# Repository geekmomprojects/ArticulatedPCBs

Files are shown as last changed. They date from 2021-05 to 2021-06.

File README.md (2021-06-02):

# Articulated PCBs (aka "Bendy Boards")
Design files and BOM for an articulated assembly of PCBs comprised of two-layered links that can pivot around a vertical axis, allowing the assembly to bend at every joint while still maintaining electrical contact between all of the boards in the assembly.<BR>
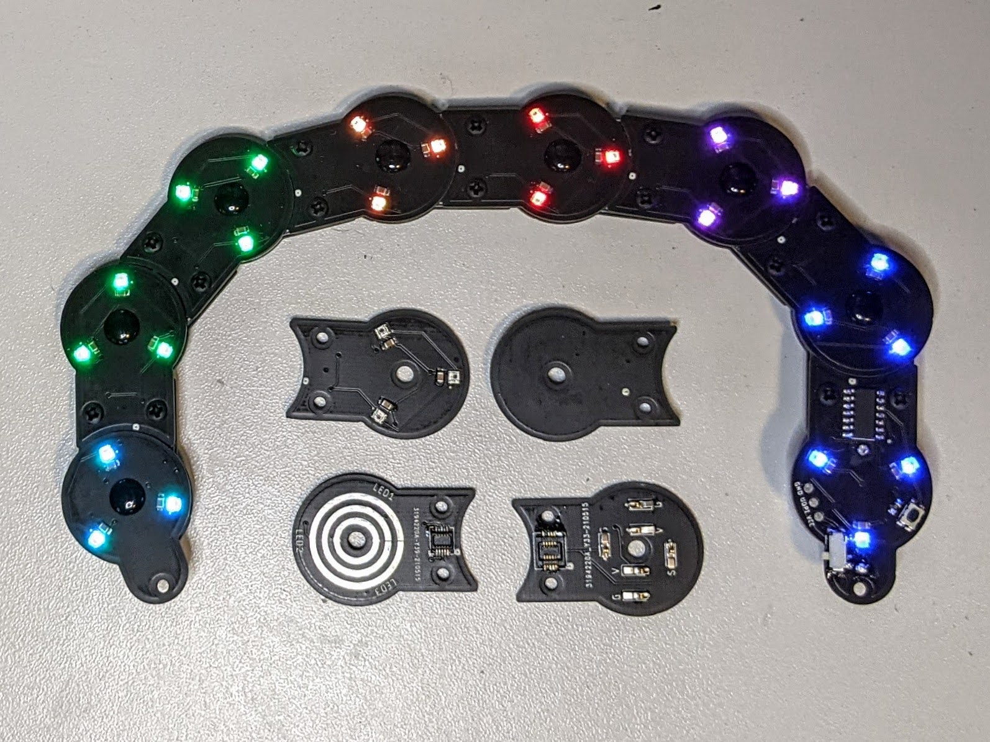
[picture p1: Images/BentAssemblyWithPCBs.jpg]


A demonstration of the boards and the assembly is on <a href="https://www.youtube.com/watch?v=9HDyzVgGNhk">YouTube:<BR> 
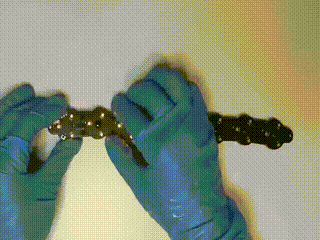
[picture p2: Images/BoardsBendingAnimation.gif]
</a>

The two layers of each link connect through pressure connectors on the bottom PCB which make contact with cocentric ring-shaped pads on the top one. A laser-cut buffer layer of 1.6mm (1/16") acrylic between the two PCBs prevents the connectors from being crushed. The connectors have a working height of 1.7 mm, which prevents the connectors from being crushed between the PCBs. The layers in the link are held together with an M3 nylon push rivet. Vertical board-to-board snap connectors connect each link to the previous one in the chain. The mating height of these snap connectors is about 1.5 mm, so the spacing between the PCB layers is the same everywhere.<BR>
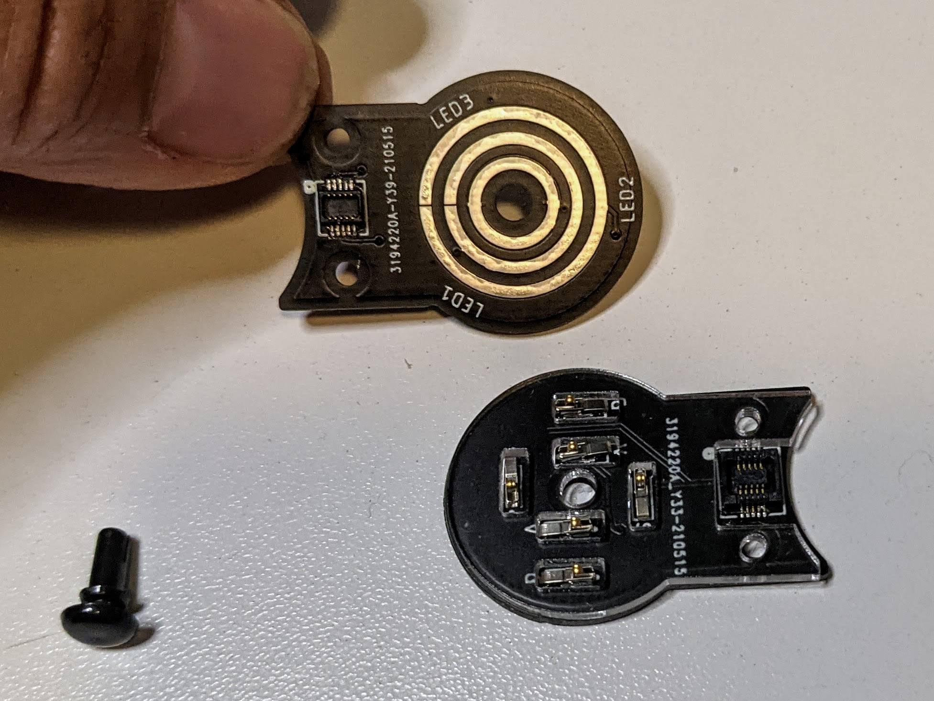
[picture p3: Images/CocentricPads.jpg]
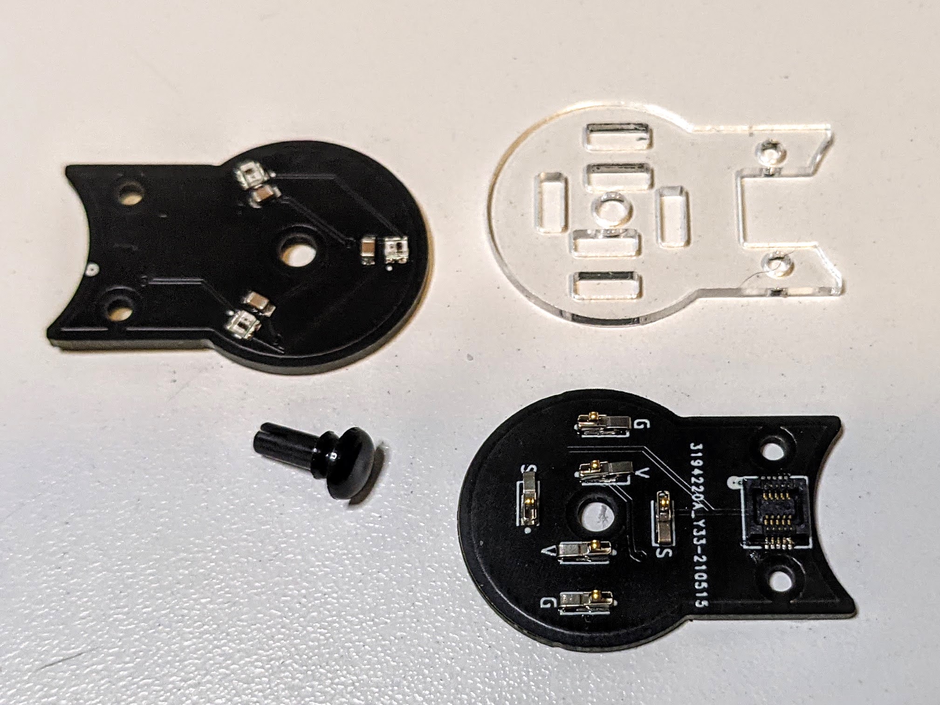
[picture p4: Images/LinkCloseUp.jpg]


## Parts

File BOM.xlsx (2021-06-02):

PCB Components | Quantity | Part Number | Datasheet | Source
WS2812 or sk6812 2020 LEDs (5 mA best) | 3 per link | WS2812 2020 |  | https://www.aliexpress.com/item/32876876257.html
0603 0.1uF capacitors | 3 per link | EMK107B7104KAHT | https://www.mouser.com/datasheet/2/396/taiyo_yuden_12132018_mlcc11_hq_e-1510082.pdf | https://www.mouser.com/ProductDetail/Taiyo-Yuden/EMK107B7104KAHT
Pressure Contacts | 6 per link | 10104319-009RLF | https://cdn.amphenol-icc.com/media/wysiwyg/files/drawing/10104319.pdf | https://www.digikey.com/product-detail/en/amphenol-icc-fci/10104319-009RLF/609-5377-1-ND/8555648
ATTiny 1604 or 1614 controller IC | 1 per assembly |  | https://www.mouser.com/datasheet/2/268/ATtiny804_1604_Data_Sheet_40002028A-1588519.pdf | https://www.mouser.com/ProductDetail/Microchip-Technology/ATTINY1604-SSNR
Slide Switch | 1 per assembly | PCM12SMTR | https://www.mouser.com/datasheet/2/60/pcm-1841544.pdf | https://www.mouser.com/ProductDetail/CK/PCM12SMTR
2xCR2032 battery holder | 1 per assembly | BH800s | https://media.digikey.com/pdf/Data%20Sheets/Memory%20Protection%20PDFs/Coin_Cell_Guide.pdf | https://www.digikey.com/en/products/detail/mpd-memory-protection-devices/BH800S/221549
Momentary push button | 1 per assembly | KMR211GLFS | https://www.ckswitches.com/media/1479/kmr2.pdf | https://www.digikey.com/en/products/detail/c-k/KMR211GLFS/550461
Board to Board connector (plug) | 1 per link | DF23C-10DS-0.5V(51) | https://www.hirose.com/product/download/?distributor=digikey&type=specSheet&lang=en&num=DF23C-10DS-0.5V(51) | https://www.digikey.com/en/products/detail/hirose-electric-co-ltd/DF23C-10DS-0.5V(51)/5155992
Board to Board connector (receptacle) | 1 per link | DF23C-10DP-0.5V(92) | https://www.hirose.com/product/download/?distributor=digikey&type=specSheet&lang=en&num=DF23C-10DP-0.5V(92) | https://www.digikey.com/en/products/detail/hirose-electric-co-ltd/DF23C-10DP-0.5V(92)/3830805
Hardware
6mm or 8mm M2 screws | 2 per link
M2 nuts | 2 per link
M3 Plastic Push Rivets for panel thickness of 5.8 mm | 1 per link |  |  | https://www.amazon.com/gp/product/B07RGKP96K
Materials
1/16" (1.6mm) acrylic for laser-cut buffer layer | 1 buffer per link

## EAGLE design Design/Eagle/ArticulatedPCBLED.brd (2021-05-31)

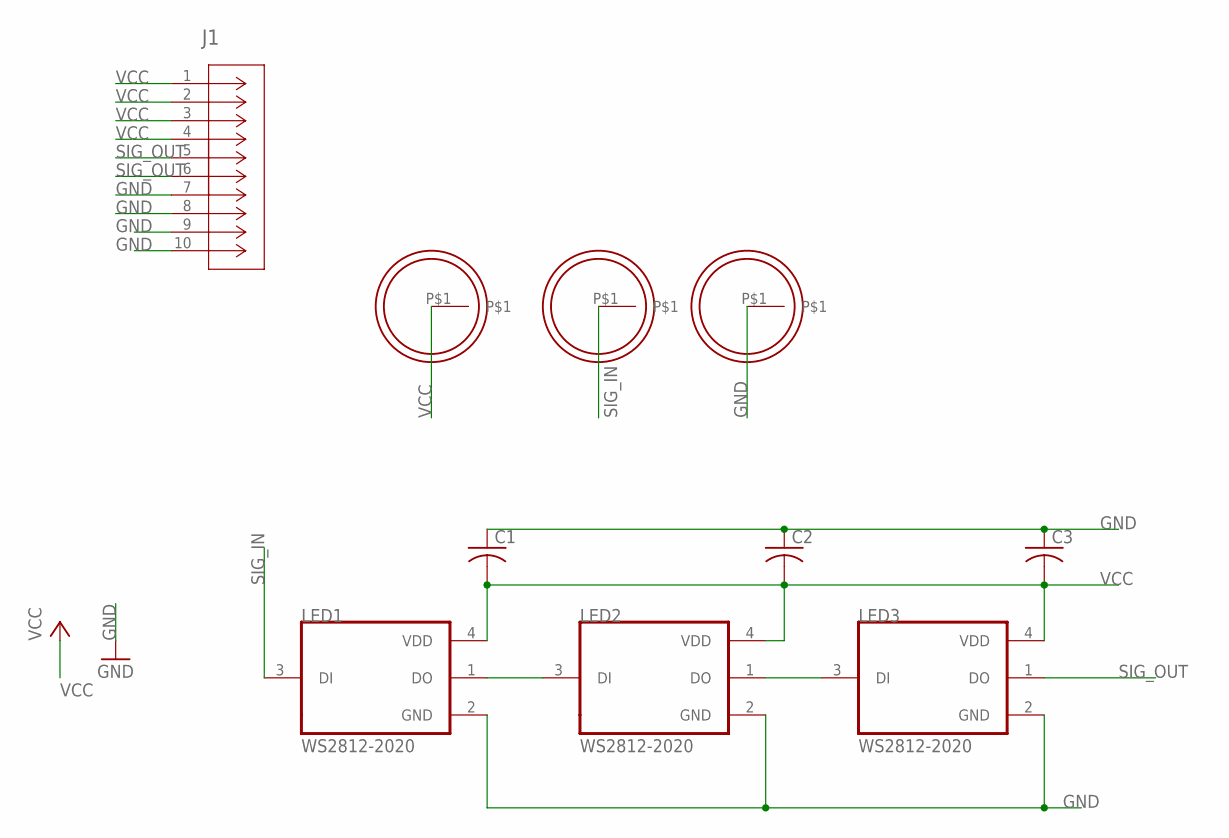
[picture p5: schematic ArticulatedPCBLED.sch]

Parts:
C1, C2, C3: C-USC0603; C0603
J1: DF23C-10DP-0.5V(92); CONN_DF23C-10DP-0.5V(92)_HIR
LED1, LED2, LED3: WS2812-2020; LED_WS2812-2020
U$2: CIRCLE_PAD_17_2_OD
U$3: CIRCLE_PAD_8_2_OD
U$4: CIRCLE_PAD_12_7_OD

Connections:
GND: C1.1, C2.1, C3.1, J1.7, J1.8, J1.9, J1.10, LED1.2 (GND), LED2.2 (GND), LED3.2 (GND), U$2.P$1
unnamed: LED1.1 (DO), LED2.3 (DI)
unnamed: LED2.1 (DO), LED3.3 (DI)
SIG_IN: LED1.3 (DI), U$4.P$1
SIG_OUT: J1.5, J1.6, LED3.1 (DO)
VCC: C1.2, C2.2, C3.2, J1.1, J1.2, J1.3, J1.4, LED1.4 (VDD), LED2.4 (VDD), LED3.4 (VDD), U$3.P$1

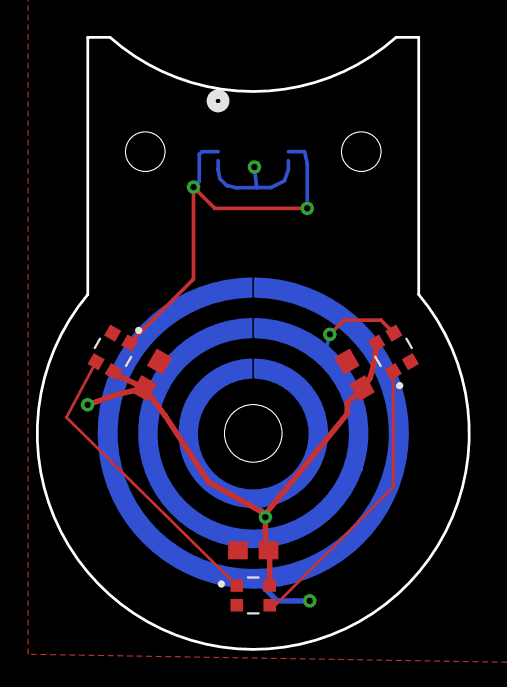
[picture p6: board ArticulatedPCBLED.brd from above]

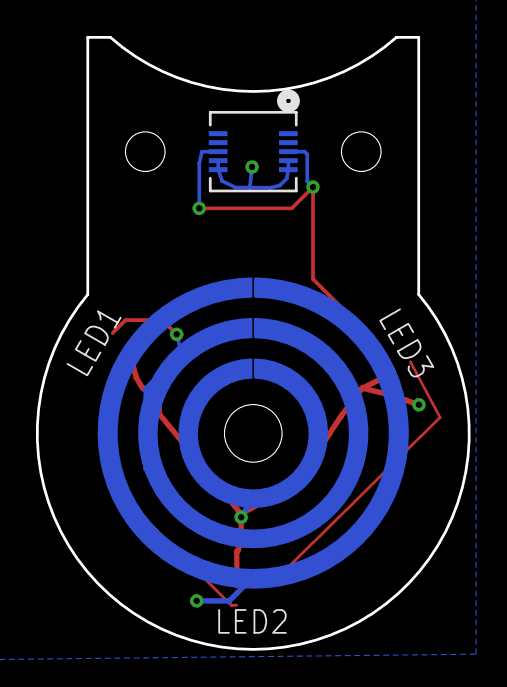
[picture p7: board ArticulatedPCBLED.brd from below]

Board: 2 copper layers, 24.0 x 34.0 mm, 10 parts (4 on the bottom side), 6 nets.

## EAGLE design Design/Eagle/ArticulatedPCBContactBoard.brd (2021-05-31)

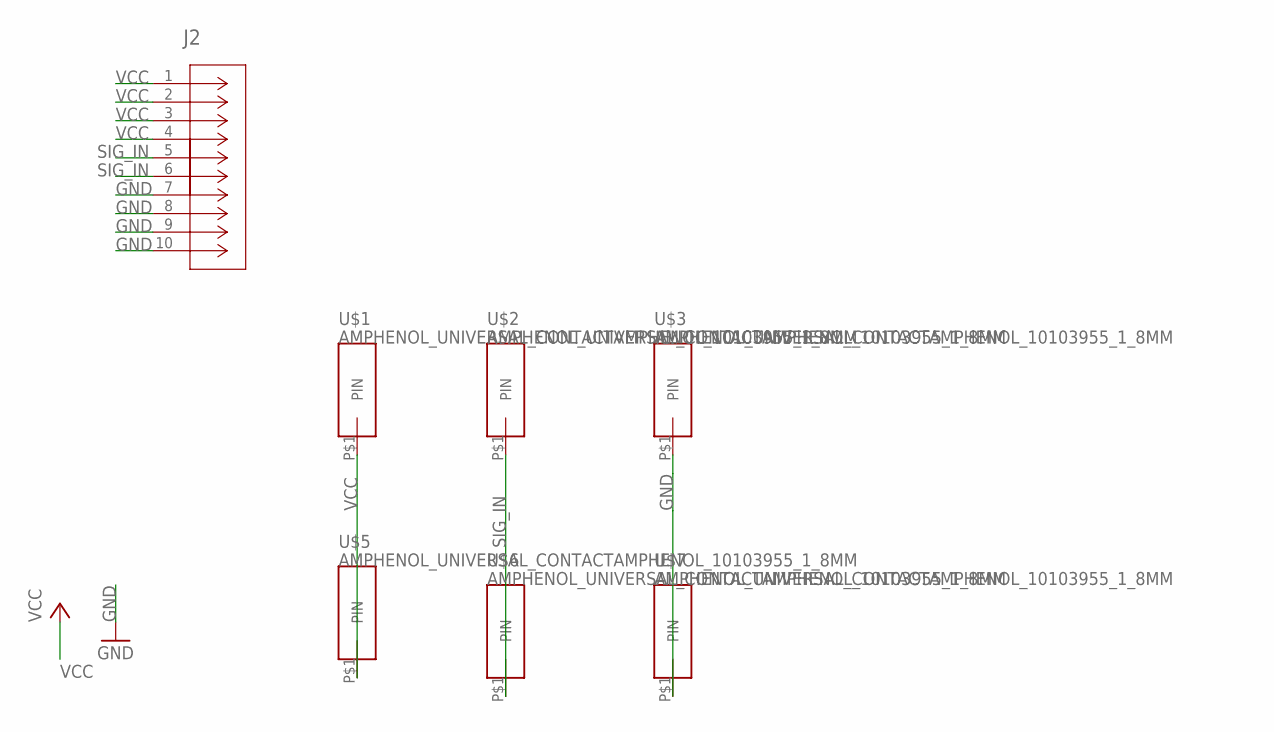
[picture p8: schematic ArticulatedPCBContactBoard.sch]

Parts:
J2: DF23C-10DS-0.5V(51); CONN_DF23C-10DS-0.5V(51)_HIR
U$1, U$2, U$3, U$5, U$6, U$7: AMPHENOL_UNIVERSAL_CONTACTAMPHENOL_10103955_1_8MM; AMPHENOL10103955

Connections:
GND: J2.7, J2.8, J2.9, J2.10, U$3.P$1, U$7.P$1
SIG_IN: J2.5, J2.6, U$2.P$1, U$6.P$1
VCC: J2.1, J2.2, J2.3, J2.4, U$1.P$1, U$5.P$1

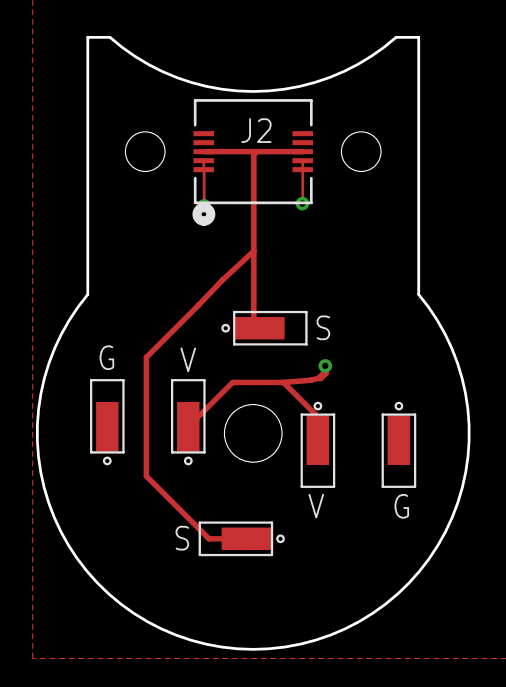
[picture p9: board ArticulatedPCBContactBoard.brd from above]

Board: 2 copper layers, 24.0 x 34.0 mm, 7 parts (0 on the bottom side), 3 nets.

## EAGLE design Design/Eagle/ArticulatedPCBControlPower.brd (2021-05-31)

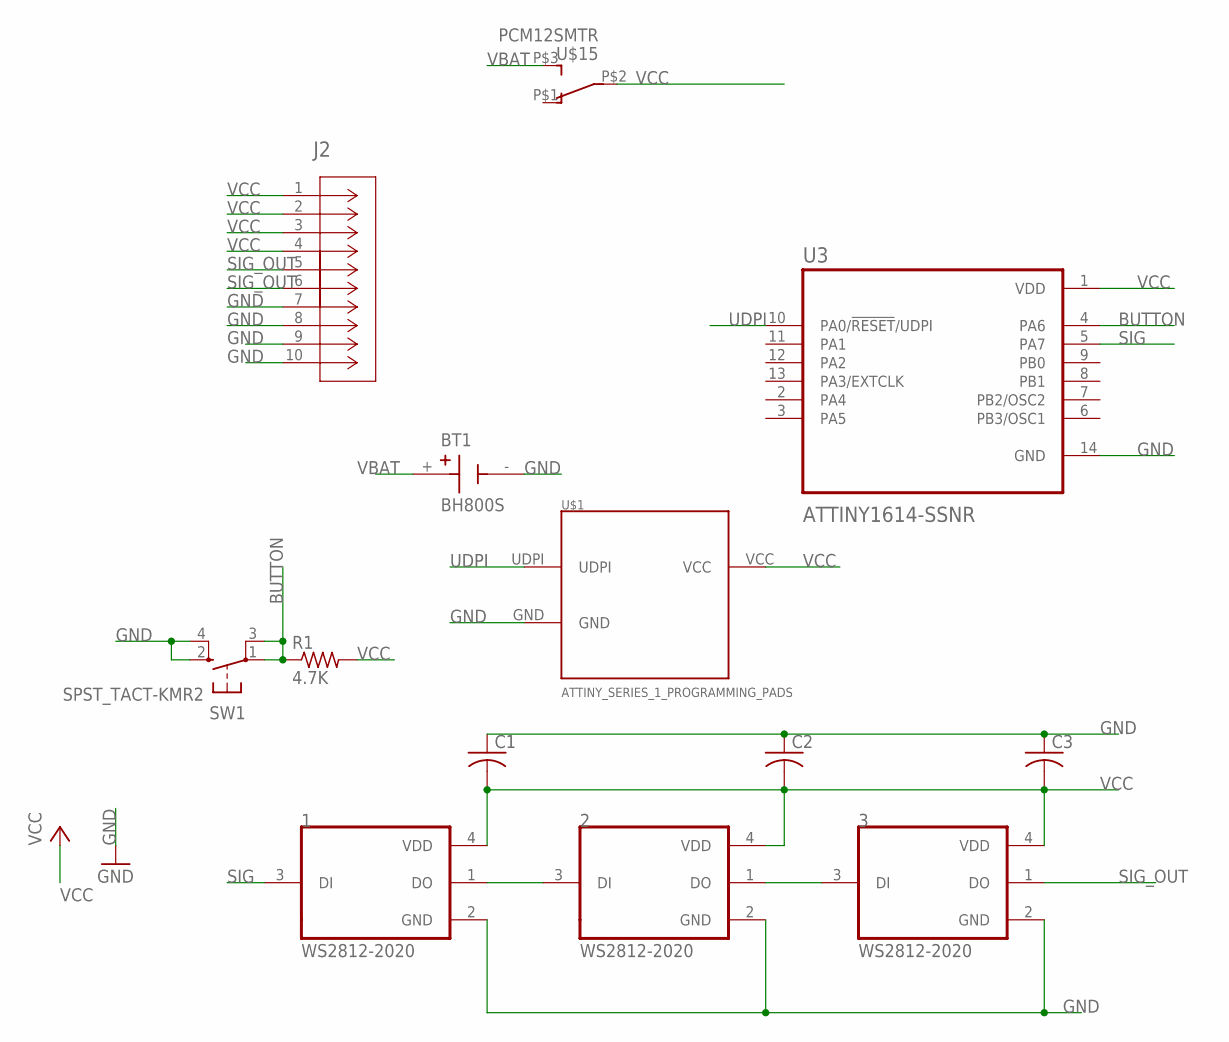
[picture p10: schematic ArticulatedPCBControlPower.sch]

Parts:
1, 2, 3: WS2812-2020; LED_WS2812-2020
BT1: BH800S; BAT_BH800S
C1, C2, C3: C-USC0603; C0603
J2: DF23C-10DP-0.5V(92); CONN_DF23C-10DP-0.5V(92)_HIR
R1: 4.7K; R0603
SW1: SPST_TACT-KMR2; KMR2
U3: ATTINY1614-SSNR; SOIC127P600X175-14N
U$1: ATTINY_SERIES_1_PROGRAMMING_PADS
U$15: PCM12SMTR

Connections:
BUTTON: R1.1, SW1.1, SW1.3 (P1), U3.4 (PA6)
GND: 1.2 (GND), 2.2 (GND), 3.2 (GND), BT1.-, C1.1, C2.1, C3.1, J2.7, J2.8, J2.9, J2.10, SW1.2 (S), SW1.4 (S1), U3.14 (GND), U$1.GND
unnamed: 1.1 (DO), 2.3 (DI)
unnamed: 2.1 (DO), 3.3 (DI)
SIG: 1.3 (DI), U3.5 (PA7)
SIG_OUT: 3.1 (DO), J2.5, J2.6
UDPI: U3.10 (PA0/!RESET!/UDPI), U$1.UDPI
VBAT: BT1.+, U$15.P$3 (3)
VCC: 1.4 (VDD), 2.4 (VDD), 3.4 (VDD), C1.2, C2.2, C3.2, J2.1, J2.2, J2.3, J2.4, R1.2, U3.1 (VDD), U$1.VCC, U$15.P$2 (2)

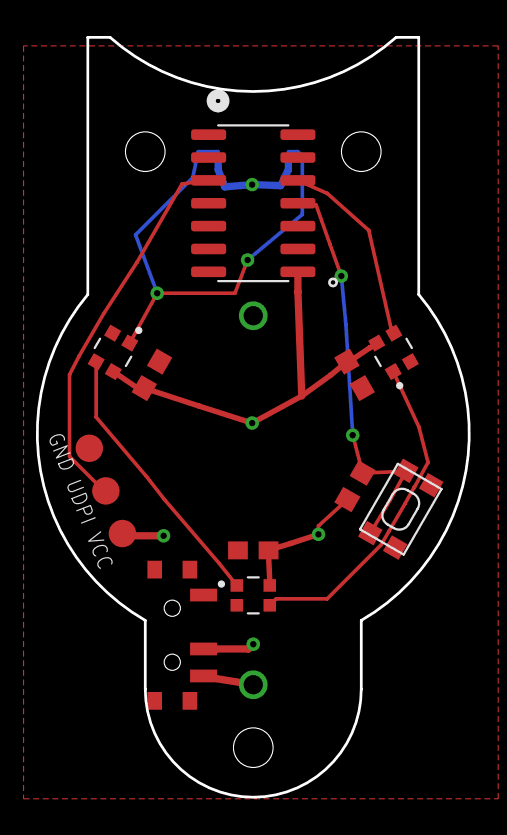
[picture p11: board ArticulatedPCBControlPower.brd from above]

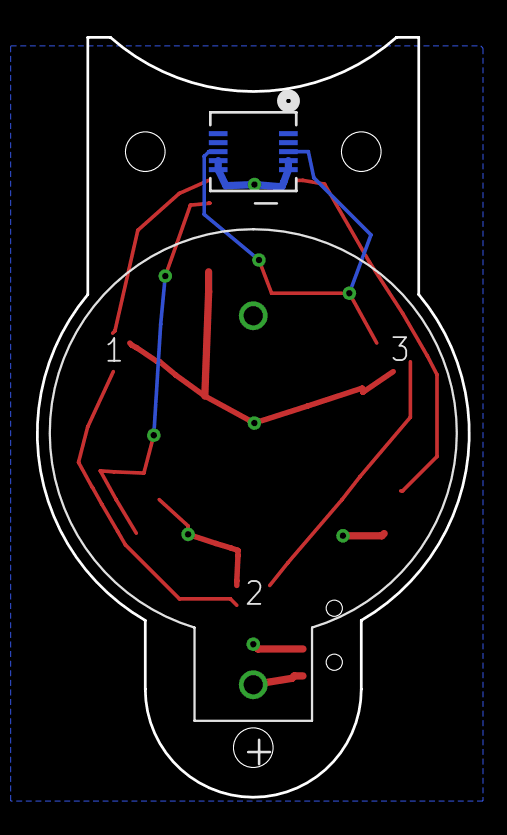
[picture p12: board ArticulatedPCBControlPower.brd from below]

Board: 2 copper layers, 24.0 x 42.2 mm, 13 parts (2 on the bottom side), 9 nets.

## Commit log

2021-06-02 Added BOM
    [BOM.xlsx]
2021-06-02 Update BOM.xlsx
    Add board to board connectors
    [BOM.xlsx]
2021-06-02 Add acrylic buffer design
    Add SVG file for laser cutting acrylic buffer layer
    [BOM.xlsx]

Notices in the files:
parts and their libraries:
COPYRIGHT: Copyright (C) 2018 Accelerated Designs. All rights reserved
